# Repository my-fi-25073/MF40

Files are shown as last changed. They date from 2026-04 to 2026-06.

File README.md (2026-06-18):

# MF40 PCB Project

[한국어 README](README.ko.md)

MF40 is my-fi's mini 40% custom keyboard PCB family. The variants share the same general design direction, but differ by horizontal width, column configuration, and bottom-row style.

This repository contains the hardware design files, QMK/VIA firmware source files, and sample plate drawing files for the MF40 PCBs.

## Type

The type indicates the PCB width and layout configuration.

* `12` / `13`: Indicates the horizontal PCB length in Cherry MX unit increments.
* `A`: Indicates a configuration where the horizontal width is fully filled with 1u columns.
* `B`: Indicates a configuration with one fewer column than the `A` configuration at the same horizontal width.
* `W`: Indicates support for a full WK-style bottom row.
* `H`: Indicates support for a 1.125u HHKB-style bottom row.

## Variants

| Variant | Layout Configuration | Main Layout Options |
| --- | --- | --- |
| `MF40-R12AW` | 12u, 12-column, WK-style layout | 3-split spacebar, 4.5u, 5u, or 7u spacebar |
| `MF40-R13AH` | 13u, 13-column, HHKB-style layout | Split or 2u Backspace, 6.25u or split spacebar |
| `MF40-R13AW` | 13u, 13-column, WK-style layout | Split or 2u Backspace, 6u or split spacebar |
| `MF40-R13BW` | 13u, 12-column, WK-style layout | ANSI/ISO/split/BAE Enter, left/right Shift options, 6u or split spacebar |

## Repository Structure

```text
KicadFiles/       KiCad schematic and PCB files
FirmwareFiles/    QMK/VIA firmware source folders
PlateFiles/       DXF plate drawing files
OtherFiles/       Other project files
```

## Firmware

Each firmware folder under `FirmwareFiles/` corresponds to one PCB variant. To compile the firmware, copy the relevant folder into QMK's `keyboards/` directory.

The firmware supports VIA and custom LED control.

## Hardware

Each PCB variant is managed as an independent KiCad project under `KicadFiles/`. If production outputs are available, they are placed in the `production/` directory of each variant.

## License

See [LICENSE](LICENSE).

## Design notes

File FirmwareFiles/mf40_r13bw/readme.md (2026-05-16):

# 900than9

900than9

*A short description of the keyboard/project*

* Keyboard Maintainer: [my-fi](https://github.com/my-fi)
* Hardware Supported: *The PCBs, controllers supported*
* Hardware Availability: *Links to where you can find this hardware*

Make example for this keyboard (after setting up your build environment):

    make 900than9:default

Flashing example for this keyboard:

    make 900than9:default:flash

See the [build environment setup](https://docs.qmk.fm/#/getting_started_build_tools) and the [make instructions](https://docs.qmk.fm/#/getting_started_make_guide) for more information. Brand new to QMK? Start with our [Complete Newbs Guide](https://docs.qmk.fm/#/newbs).

## Bootloader

Enter the bootloader in 3 ways:

* **Bootmagic reset**: Hold down the key at (0,0) in the matrix (usually the top left key or Escape) and plug in the keyboard
* **Physical reset button**: Briefly press the button on the back of the PCB - some may have pads you must short instead
* **Keycode in layout**: Press the key mapped to `QK_BOOT` if it is available

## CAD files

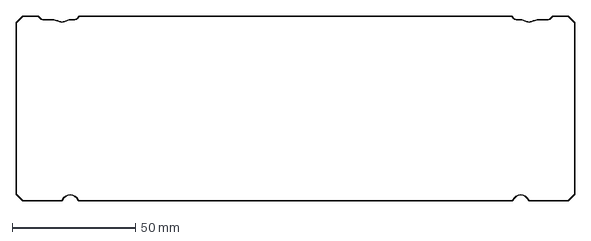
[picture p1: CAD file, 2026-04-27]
Otherfiles/outline-12u.dxf
226.7 x 75.0 mm

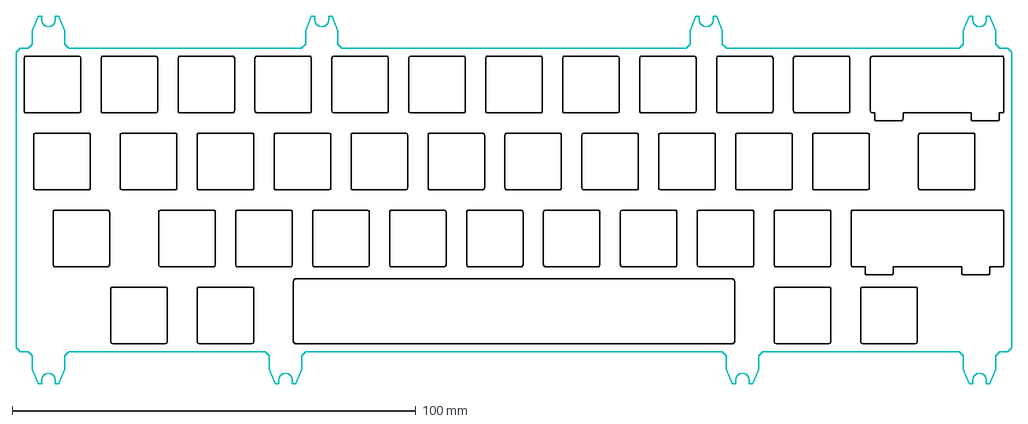
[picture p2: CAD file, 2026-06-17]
PlateFiles/Kkangmini_Plate_R13AH.dxf
246.6 x 91.1 mm

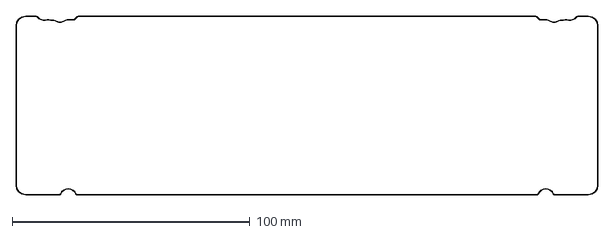
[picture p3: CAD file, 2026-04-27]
Otherfiles/outline-13u.dxf
245.0 x 75.0 mm

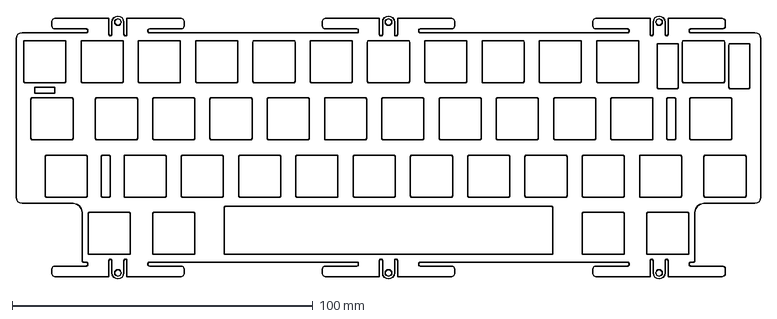
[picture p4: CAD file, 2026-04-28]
PlateFiles/Brick40-Plate-MF40_R13AH.dxf
247.7 x 87.4 mm

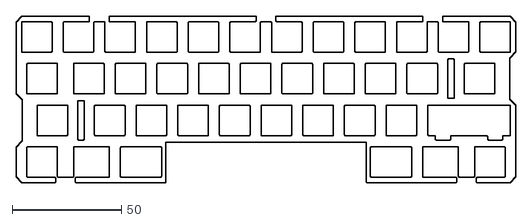
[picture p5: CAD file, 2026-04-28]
PlateFiles/F1-40-Plate-MF40_R12AW.dxf
228.6 x 76.2

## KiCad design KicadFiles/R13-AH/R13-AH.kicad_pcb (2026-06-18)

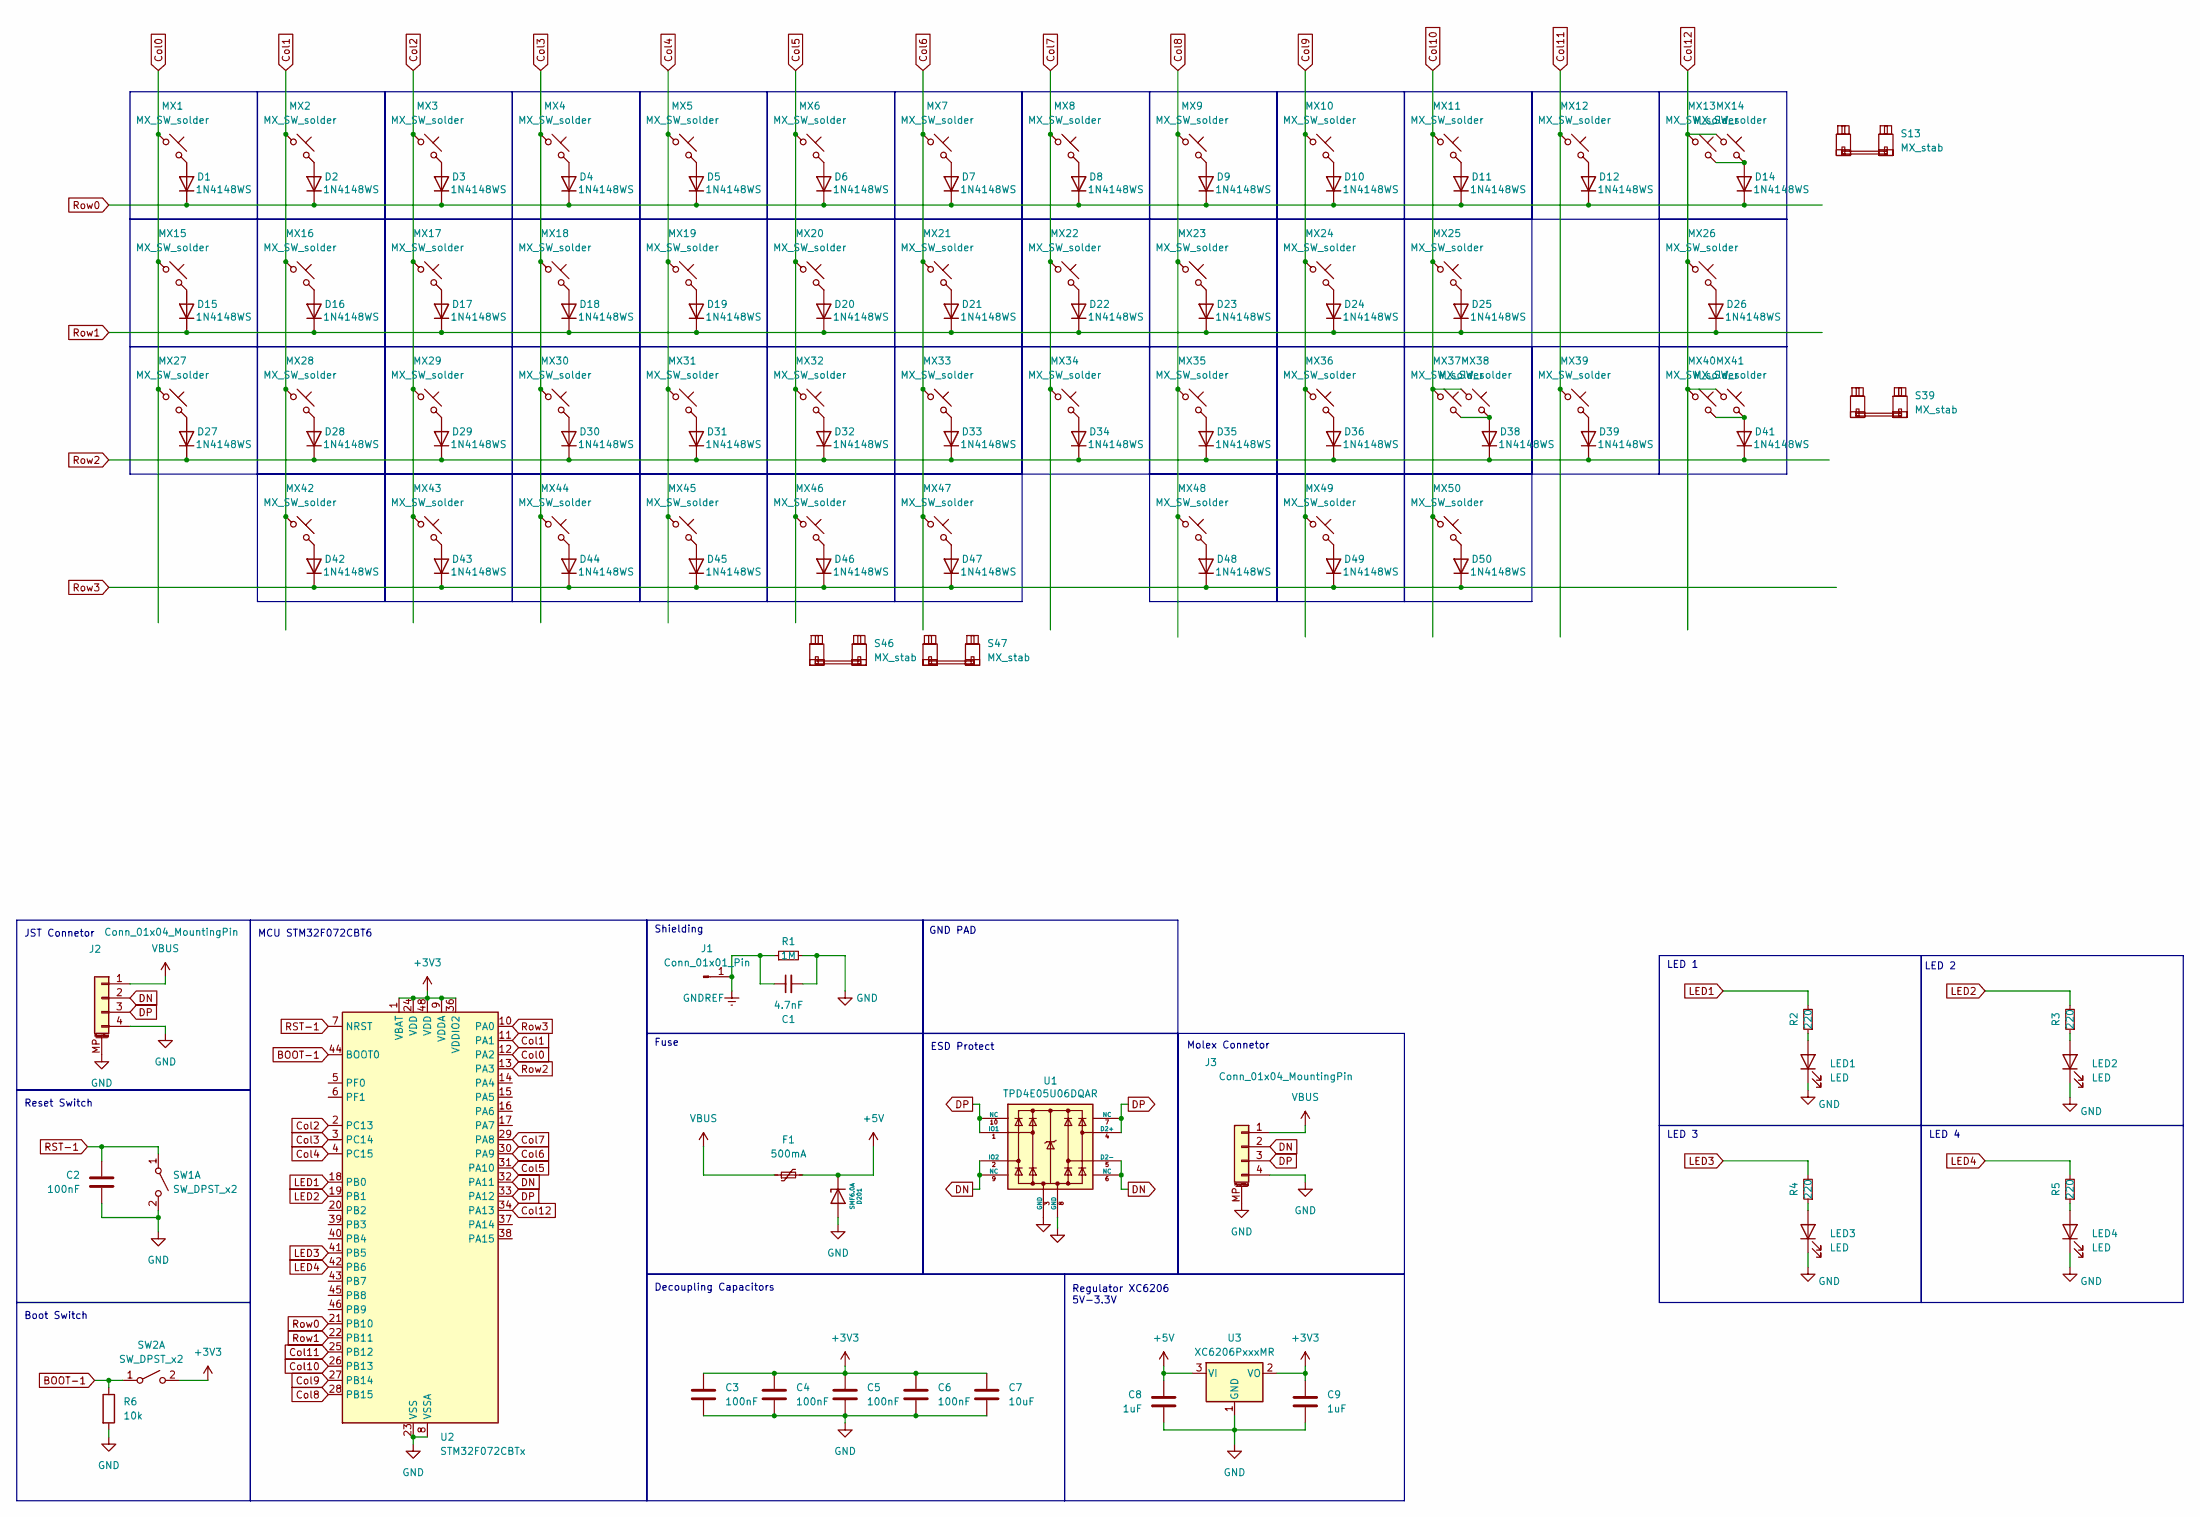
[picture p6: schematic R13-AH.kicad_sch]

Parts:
C1: 4.7nF; C_0402_1005Metric
C2, C3, C4, C5, C6: 100nF; C_0402_1005Metric
C7: 10uF; C_0402_1005Metric
C8, C9: 1uF; C_0402_1005Metric
D1, D2, D3, D4, D5, D6, D7, D8, D9, D10, D11, D12, D14, D15, D16, D17, D18, D19, D20, D21, D22, D23, D24, D25, D26, D27, D28, D29, D30, D31, D32, D33, D34, D35, D36, D38, D39, D41, D42, D43, D44, D45, D46, D47, D48, D49, D50: 1N4148WS; D_SOD-323_HandSoldering
D201: SMF6.0A; D_SOD-123; Manufacturer Part Number SMF6.0A; LCSC Part Number C708002
F1: 500mA; Fuse_1206_3216Metric; LCSC C70076
J1: Conn_01x01_Pin; TestPoint_THTPad_2.0x2.0mm_Drill1.0mm
J2: Conn_01x04_MountingPin; JST_SH_SM04B-SRSS-TB_1x04-1MP_P1.00mm_Horizontal
J3: Conn_01x04_MountingPin; Molex_Pico-EZmate_78171-0004_1x04-1MP_P1.20mm_Vertical; Manufacturer Part Number 78171-0004; LCSC Part Number C588524
LED1, LED2, LED3, LED4: LED; DIP_LED_MX_3mm
MX1, MX2, MX3, MX4, MX5, MX6, MX7, MX8, MX9, MX10, MX11, MX12, MX13, MX14, MX16, MX17, MX18, MX19, MX20, MX21, MX22, MX23, MX24, MX25, MX28, MX29, MX30, MX31, MX32, MX33, MX34, MX35, MX36, MX37, MX39, MX41, MX42, MX45, MX46, MX47, MX50: MX_SW_solder; SW_MX_1u
MX15, MX38, MX40, MX43, MX48, MX49: MX_SW_solder; SW_MX_1.25u
MX26, MX27, MX44: MX_SW_solder; SW_MX_1.75u
R1: 1M; R_0402_1005Metric
R2, R3, R4, R5: 220; R_0402_1005Metric
R6: 10k; R_0402_1005Metric
S13, S47: MX_stab; STAB_MX_2u
S39: MX_stab; STAB_MX_2.25u
S46: MX_stab; STAB_MX_6.25u
SW1, SW2: SW_DPST_x2; SW_Push_1P1T_XKB_TS-1187A; MPN C318884
U1: TPD4E05U06DQAR; USON-10_2.5x1.0mm_P0.5mm; Manufacturer Part Number TPD4E05U06DQAR; LCSC Part Number C138714
U2: STM32F072CBTx; LQFP-48_7x7mm_P0.5mm; MPN C81720
U3: XC6206PxxxMR; SOT-23-3; MPN C5148692

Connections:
+3V3: C3.1, C4.1, C5.1, C6.1, C7.1, C9.1, SW2.2 (B), U2.1 (VBAT), U2.9 (VDDA), U2.24 (VDD), U2.36 (VDDIO2), U2.48 (VDD), U3.2 (VO)
+5V: C8.1, D201.1 (K), F1.2, U3.3 (VI)
BOOT-1: R6.1, SW2.1 (A), U2.44 (BOOT0)
Col0: MX1.1, MX15.1, MX27.1, U2.12 (PA2)
Col1: MX2.1, MX16.1, MX28.1, MX42.1, U2.11 (PA1)
Col2: MX3.1, MX17.1, MX29.1, MX43.1, U2.2 (PC13)
Col3: MX4.1, MX18.1, MX30.1, MX44.1, U2.3 (PC14)
Col4: MX5.1, MX19.1, MX31.1, MX45.1, U2.4 (PC15)
Col5: MX6.1, MX20.1, MX32.1, MX46.1, U2.31 (PA10)
Col6: MX7.1, MX21.1, MX33.1, MX47.1, U2.30 (PA9)
Col7: MX8.1, MX22.1, MX34.1, U2.29 (PA8)
Col8: MX9.1, MX23.1, MX35.1, MX48.1, U2.28 (PB15)
Col9: MX10.1, MX24.1, MX36.1, MX49.1, U2.27 (PB14)
Col10: MX11.1, MX25.1, MX37.1, MX38.1, MX50.1, U2.26 (PB13)
Col11: MX12.1, MX39.1, U2.25 (PB12)
Col12: MX13.1, MX14.1, MX26.1, MX40.1, MX41.1, U2.34 (PA13)
DN: J2.2, J3.2, U1.2 (IO2), U1.5 (D2-), U1.6 (NC), U1.9 (NC), U2.32 (PA11)
DP: J2.3, J3.3, U1.1 (IO1), U1.4 (D2+), U1.7 (NC), U1.10 (NC), U2.33 (PA12)
GND: C1.2, C2.2, C3.2, C4.2, C5.2, C6.2, C7.2, C8.2, C9.2, D201.2 (A), J2.4, J2.MP (MountPin), J3.4, J3.MP (MountPin), LED1.1 (K), LED2.1 (K), LED3.1 (K), LED4.1 (K), R1.2, R6.2, SW1.2 (B), U1.3 (GND), U1.8 (GND), U2.8 (VSSA), U2.23 (VSS), U2.35 (VSS), U2.47 (VSS), U3.1 (GND)
GNDREF: C1.1, J1.1, R1.1
LED1: R2.2, U2.18 (PB0)
LED2: R3.2, U2.19 (PB1)
LED3: R4.2, U2.41 (PB5)
LED4: R5.2, U2.42 (PB6)
unnamed: D1.2 (A), MX1.2
unnamed: D2.2 (A), MX2.2
unnamed: D3.2 (A), MX3.2
unnamed: D4.2 (A), MX4.2
unnamed: D5.2 (A), MX5.2
unnamed: D6.2 (A), MX6.2
unnamed: D7.2 (A), MX7.2
unnamed: D8.2 (A), MX8.2
unnamed: D9.2 (A), MX9.2
unnamed: D10.2 (A), MX10.2
unnamed: D11.2 (A), MX11.2
unnamed: D12.2 (A), MX12.2
unnamed: D14.2 (A), MX13.2, MX14.2
unnamed: D15.2 (A), MX15.2
unnamed: D16.2 (A), MX16.2
unnamed: D17.2 (A), MX17.2
unnamed: D18.2 (A), MX18.2
unnamed: D19.2 (A), MX19.2
unnamed: D20.2 (A), MX20.2
unnamed: D21.2 (A), MX21.2
unnamed: D22.2 (A), MX22.2
unnamed: D23.2 (A), MX23.2
unnamed: D24.2 (A), MX24.2
unnamed: D25.2 (A), MX25.2
unnamed: D26.2 (A), MX26.2
unnamed: D27.2 (A), MX27.2
unnamed: D28.2 (A), MX28.2
unnamed: D29.2 (A), MX29.2
unnamed: D30.2 (A), MX30.2
unnamed: D31.2 (A), MX31.2
unnamed: D32.2 (A), MX32.2
unnamed: D33.2 (A), MX33.2
unnamed: D34.2 (A), MX34.2
unnamed: D35.2 (A), MX35.2
unnamed: D36.2 (A), MX36.2
unnamed: D38.2 (A), MX37.2, MX38.2
unnamed: D39.2 (A), MX39.2
unnamed: D41.2 (A), MX40.2, MX41.2
unnamed: D42.2 (A), MX42.2
unnamed: D43.2 (A), MX43.2
unnamed: D44.2 (A), MX44.2
unnamed: D45.2 (A), MX45.2
unnamed: D46.2 (A), MX46.2
unnamed: D47.2 (A), MX47.2
unnamed: D48.2 (A), MX48.2
unnamed: D49.2 (A), MX49.2
unnamed: D50.2 (A), MX50.2
unnamed: LED1.2 (A), R2.1
unnamed: LED2.2 (A), R3.1
unnamed: LED3.2 (A), R4.1
unnamed: LED4.2 (A), R5.1
RST-1: C2.1, SW1.1 (A), U2.7 (NRST)
Row0: D1.1 (K), D2.1 (K), D3.1 (K), D4.1 (K), D5.1 (K), D6.1 (K), D7.1 (K), D8.1 (K), D9.1 (K), D10.1 (K), D11.1 (K), D12.1 (K), D14.1 (K), U2.21 (PB10)
Row1: D15.1 (K), D16.1 (K), D17.1 (K), D18.1 (K), D19.1 (K), D20.1 (K), D21.1 (K), D22.1 (K), D23.1 (K), D24.1 (K), D25.1 (K), D26.1 (K), U2.22 (PB11)
Row2: D27.1 (K), D28.1 (K), D29.1 (K), D30.1 (K), D31.1 (K), D32.1 (K), D33.1 (K), D34.1 (K), D35.1 (K), D36.1 (K), D38.1 (K), D39.1 (K), D41.1 (K), U2.13 (PA3)
Row3: D42.1 (K), D43.1 (K), D44.1 (K), D45.1 (K), D46.1 (K), D47.1 (K), D48.1 (K), D49.1 (K), D50.1 (K), U2.10 (PA0)
VBUS: F1.1, J2.1, J3.1

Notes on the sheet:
Regulator XC6206 5V-3.3V
Molex Connetor
ESD Protect
JST Connetor
GND PAD
LED 2
Boot Switch
LED 1
Decoupling Capacitors
LED 4
MCU STM32F072CBT6
LED 3
Fuse
Reset Switch
Shielding

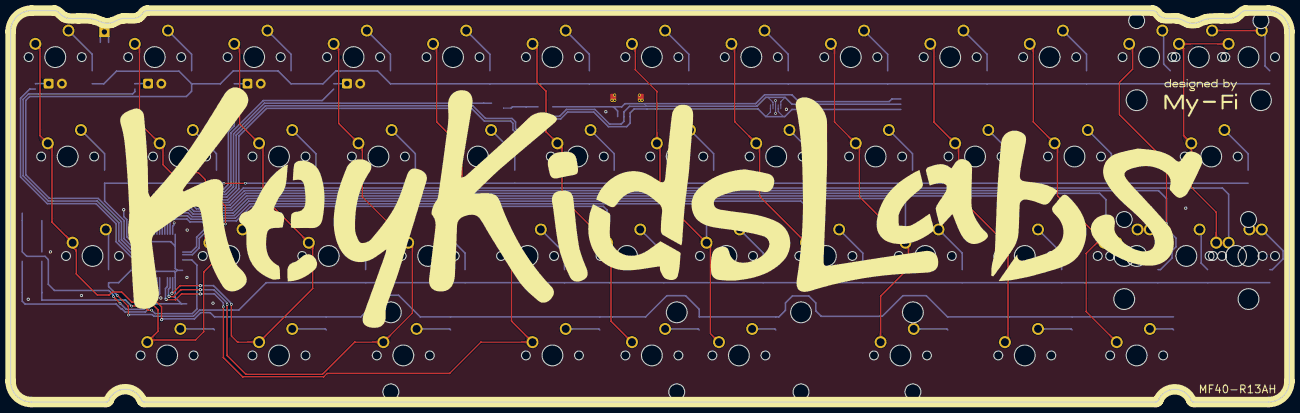
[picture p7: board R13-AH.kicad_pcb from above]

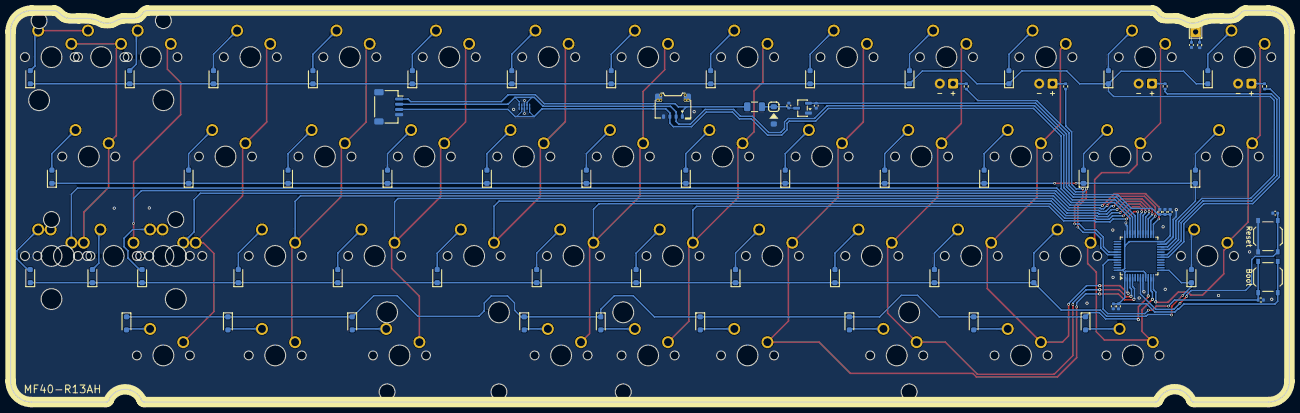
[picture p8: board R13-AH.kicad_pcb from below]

Board: 2 copper layers, 245.0 x 75.0 mm, 130 parts (72 on the bottom side), 81 nets.

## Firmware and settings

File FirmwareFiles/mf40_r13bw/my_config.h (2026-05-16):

#pragma once

#include "quantum.h"

#define MY_CONFIG_VERSION 5u
#define MY_CONFIG_LED_COUNT 5u
#define MY_CONFIG_INDICATOR_SOURCE_MAX IND_LAYER3

typedef enum {
    IND_NONE = 0,
    IND_SCROLL = 1,
    IND_CAPS = 2,
    IND_NUM = 3,
    IND_KANA = 4,
    IND_LAYER0 = 5,
    IND_LAYER1,
    IND_LAYER2,
    IND_LAYER3,
} my_indicator_source_t;

typedef struct __attribute__((packed)) {
    uint8_t version;
    uint8_t led_flags[MY_CONFIG_LED_COUNT];
    uint8_t indicator_source[MY_CONFIG_LED_COUNT];
} my_config_t;

extern my_config_t g_my_config;

void my_config_save(void);

#ifdef VIA_ENABLE
enum custom_value_id {
    // VIA 커스텀 값: LED 0/1/2/3/CAPS 이펙트
    id_custom_led_flags_0 = 1,
    id_custom_led_flags_1 = 2,
    id_custom_led_flags_2 = 3,
    id_custom_led_flags_3 = 4,
    id_custom_led_flags_4 = 5,
    // VIA 커스텀 값: LED 0/1/2/3/CAPS 인디케이터 선택
    id_custom_indicator_0 = 6,
    id_custom_indicator_1 = 7,
    id_custom_indicator_2 = 8,
    id_custom_indicator_3 = 9,
    id_custom_indicator_4 = 10,
};
#endif

// LED 인덱스 순서 사용: 0:B0(LED1), 1:B1(LED2), 2:B5(LED3), 3:B6(LED4), 4:A5(LED_CAPS)
uint8_t my_config_get_led_flags(uint8_t idx);
void my_config_set_led_flags(uint8_t idx, uint8_t flags);

// 인디케이터 get/set
uint8_t my_config_get_indicator(uint8_t idx);
void my_config_set_indicator(uint8_t idx, uint8_t indicator);

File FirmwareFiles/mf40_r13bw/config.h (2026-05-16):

#pragma once

// LED Pins: B0(LED1), B1(LED2), B5(LED3), B6(LED4), A5(LED_CAPS)

// // LED Indicators 설정
// #define LED_1_PIN B0
// #define LED_2_PIN B1
// #define LED_3_PIN B5
// #define LED_4_PIN B6
// #define LED_CAPS_PIN A5

// // LED가 켜질 때의 핀 상태 (1: HIGH, 0: LOW)
// #define LED_PIN_ON_STATE 1

/* 백라이트 설정 - 현재 비활성화 */
// #define BACKLIGHT_PIN A6
// #define BACKLIGHT_LEVELS 1

#define DYNAMIC_KEYMAP_LAYER_COUNT 6
#define VIA_EEPROM_CUSTOM_CONFIG_SIZE 32
#define EECONFIG_KB_DATA_SIZE VIA_EEPROM_CUSTOM_CONFIG_SIZE
#define VIA_FIRMWARE_VERSION 0x00000001

#define USB_POLLING_INTERVAL_MS 1

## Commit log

2026-04-15 Add README overview for MF40 PCB project
2026-04-16 Add keyboard layout JSON files for 12u and 13u configurations
    - Created 12u-40p-keyboard-layout.json with detailed key specifications.
    - Created 13u-40p-keyboard-layout.json with comprehensive key dimensions and attributes.
    [R12-AW.kicad_pcb, R12-AW.kicad_sch, R13-AH.kicad_pcb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]
2026-04-27 Add and update KiCad design assets for R12/R13 variants
    - refresh existing R12-AW, R13-AH, and R13-BW project files
    - add the R13-AW project and variant-specific placer configs
    - add 12u/13u outlines and normalize layout JSON filenames
    [R12-AW.kicad_pcb, R13-AH.kicad_pcb, R13-AH.kicad_sch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]
2026-04-28 Add junctions and wires to R13-BW schematic for improved connectivity
    - Added a junction at (300.99, 62.23) to enhance signal routing.
    - Introduced a junction at (306.07, 67.31) for better circuit integration.
    - Removed unnecessary junction at (299.72, 44.45) to clean up the schematic.
    - Updated wire connections to reflect new junction placements and maintain circuit integrity.
    [R13-AH.kicad_pcb, R13-AW.kicad_pcb, R13-BW.kicad_pcb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]
2026-04-28 Implement feature X to enhance user experience and optimize performance
    [R13-BW.kicad_pcb]
2026-04-28 Refactor code structure for improved readability and maintainability
    [Brick40-Plate-MF40_R13AH.dxf, F1-40-Plate-MF40_R12AW.dxf]
2026-04-29 Add global labels for columns and rows in R13-AH schematic
    - Introduced new global labels for columns (Col0 to Col12) and rows (Row0 to Row3) in the R13-AH schematic.
    - Each label includes properties for intersheet references, font size, justification, and positioning.
    - Enhanced organization and readability of the schematic by clearly defining input and output connections.
    [R12-AW.kicad_pcb, R13-AH.kicad_pcb, R13-AH.kicad_sch]
2026-05-03 Update DRC exclusions and modify error handling in R13-AH.kicad_pro
    - Added multiple DRC exclusions for specific footprints and hole clearances.
    - Changed DRC error handling settings for courtyards overlap, hole to hole, nonmirrored text on back layer, silk edge clearance, silk over copper, and silk overlap to "ignore".
    - Updated solder mask to copper clearance from 0.0 to 0.005.
    [R12-AW.kicad_pcb, R13-AH.kicad_pcb]
2026-05-05 Update design rules and add global labels in schematic
    - Changed design rule for "courtyards_overlap" from "error" to "ignore".
    - Updated hole clearance and hole to hole rules to "ignore".
    - Set several silk layer rules to "ignore" to reduce warnings.
    - Added multiple global labels in the schematic for better intersheet referencing, including "Col0", "Col1", "Col2", "Col3", "Col4", "Col5", "Col6", "Col7", "Col8", "Col9", "Col10", "Col11", "Col12", "Row0", "Row1", "Row2", and "Row3".
    [R13-BW.kicad_pcb, R13-BW.kicad_sch]
2026-05-06 Update design rules and add global labels in schematic
    - Changed design rule settings in R13-AW.kicad_pro to ignore several warnings and errors, including courtyard overlaps, hole clearance, silk edge clearance, and solder mask bridges.
    - Added multiple global labels in R13-AW.kicad_sch for better intersheet referencing, including Col0, Col1, Col2, Col3, Col4, Col5, Col6, Col7, Col8, Col9, Col10, Col11, Col12, Row0, Row1, Row2, and Row3.
    - Ensured proper placement and formatting for new global labels to enhance readability and maintainability of the schematic.
    [R13-AW.kicad_pcb, R13-AW.kicad_sch]
2026-05-16 Add custom keycodes and LED effects for MF40-R12AW keyboard
    - Implemented custom keycodes for various OS shortcuts including language switch, screenshot capture, and desktop navigation.
    - Created my_effect.h and my_effect.c for LED effect management, including typing hold, breathing, and indicator modes.
    - Defined keymap layers and custom keycodes in my_keycode.h for better keyboard functionality.
    - Added readme.md for project documentation and flashing instructions.
    - Configured rules.mk to enable VIA and OS detection features.
    - Created vi.json and via.json for visual representation and configuration of the keyboard layout and LED effects.
    [config.h, my_config.h]
2026-05-16 Add custom keycodes and LED effects for MF40-R13AH keyboard
    - Created my_effect.h and my_effect.c for LED effect management.
    - Implemented my_keycode.c and my_keycode.h for custom keycode handling.
    - Added rules.mk to enable VIA and OS detection features.
    - Included vi.json and via.json for keyboard layout and configuration.
    - Added a readme.md for project documentation and build instructions.
2026-05-16 Implement feature X to enhance user experience and fix bug Y in module Z
    [R12-AW.kicad_pcb]
2026-05-16 Add custom keycode functionality and supporting files for MF40-R13AW keyboard
    - Implemented custom keycodes in my_keycode.c for various OS-specific actions including language switching, screenshot capture, and desktop navigation.
    - Defined custom keycodes in my_keycode.h for easy reference and usage.
    - Created a readme.md file to provide project overview, build instructions, and bootloader entry methods.
    - Configured rules.mk to enable VIA and OS detection, and included custom source files.
    - Added vi.json and via.json files for visual representation and configuration of the keyboard layout and keycodes in VIA.
2026-05-16 Add custom keycodes and configuration for MF40-R13BW keyboard
    - Created my_keycode.h to define custom keycodes and layers.
    - Added a readme.md file with project description and build instructions.
    - Introduced rules.mk to enable VIA and OS detection features.
    - Added vi.json for visual representation of the keyboard layout.
    - Created via.json for VIA configuration including custom keycodes and LED effects.
2026-06-18 Enhance design settings in R13-BW project
    - Added options to disable default application for footprint barcodes and dimensions.
    - Updated zone settings with additional parameters including border display style, corner radius, and thermal relief specifications.
    - Introduced new warnings for footprint symbol field mismatches and missing tuning profiles.
    - Adjusted track settings to include new ignore rules for centered tracks and tuning profile geometries.
    [R13-AH.kicad_pcb]
